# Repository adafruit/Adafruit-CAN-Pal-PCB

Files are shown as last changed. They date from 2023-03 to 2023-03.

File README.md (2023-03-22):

## Adafruit CAN Pal - CAN Bus Transciever - TJA1051T/3 PCB

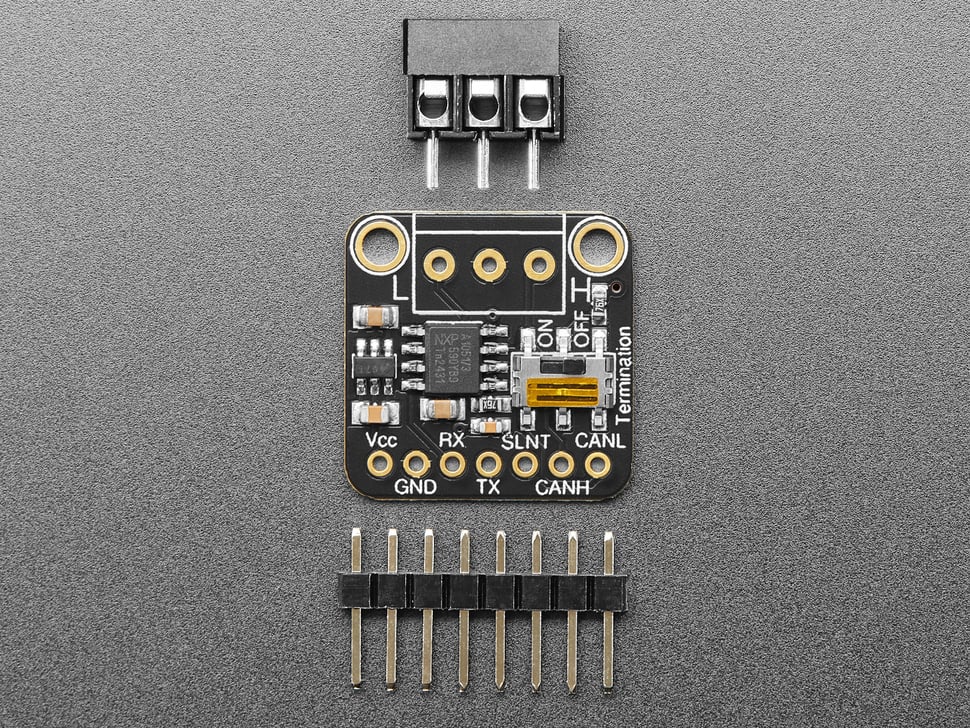
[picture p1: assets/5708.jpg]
<a href="http://www.adafruit.com/products/5708"><br/>
Click here to purchase one from the Adafruit shop</a>

PCB files for the Adafruit CAN Pal - CAN Bus Transciever - TJA1051T/3. 

Format is EagleCAD schematic and board layout
* https://www.adafruit.com/product/5708

### Description

If you'd like to connect a board with native CAN Peripheral support, the Adafruit CAN Pal Transceiver will take the 3V logic level signals and convert them to CAN logic levels with the differential signaling required to communicate. Note that not all chips have a CAN peripheral! Some that we know do have it are the ESP32/ESP32-S2/ESP32-S3 (note that ESP32 calls this interface TWAI not CAN) series of chips, SAME51, STM32F405, or Teensy 4.

Check the product documentation for the board you are wiring this to, to make sure that the chip has CAN support and the RX and TX pins are brought out for you to connect the transceiver to! Despite sharing the 'RX' and 'TX' name with UART, they're not at all the same interface.

CAN Bus is a small-scale networking standard, originally designed for cars and, yes, busses, but is now used for many robotics or sensor networks that need better range and addressing than I2C, and don't have the pins or computational ability to talk on Ethernet. CAN is 2 wire differential, which means it's good for long distances and noisy environments.

Messages are sent at about 1Mbps rate - you set the frequency for the bus and then all 'joiners' must match it, and have an address before the packet so that each node can listen in to messages just for it. New nodes can be attached easily because they just need to connect to the two data lines anywhere in the shared net. Each CAN devices sends messages whenever it wants, and thanks to some clever data encoding, can detect if there's a message collision and retransmit later. 

We've added a few nice extras to this breakout pal to make it useful in many common CAN scenarios:

* TJA1051/T3 can communicate with 3.3V~5V logic for use with modern microcontrollers. 
* 5V charge-pump voltage generator, so even though you are running 3.3V power and logic on most modern microcontroller boards, it will generate a nice clean 5V as required by the transceiver. No separate 5V power required!
* 3.5mm terminal block that can be soldered in to get quick access to the High and Low data lines as well as a ground pin.
* 2 x 60 ohm termination resistor on board (120 ohm in series), you can remove or activate the termination easily by flipping the onboard switch.

Each order comes with an assembled 'pal, terminal block and header. You will need to solder in the header yourself but its a quick task.

### License

Adafruit invests time and resources providing this open source design, please support Adafruit and open-source hardware by purchasing products from [Adafruit](https://www.adafruit.com)!

Designed by Limor Fried/Ladyada for Adafruit Industries.

Creative Commons Attribution/Share-Alike, all text above must be included in any redistribution. 
See license.txt for additional details.

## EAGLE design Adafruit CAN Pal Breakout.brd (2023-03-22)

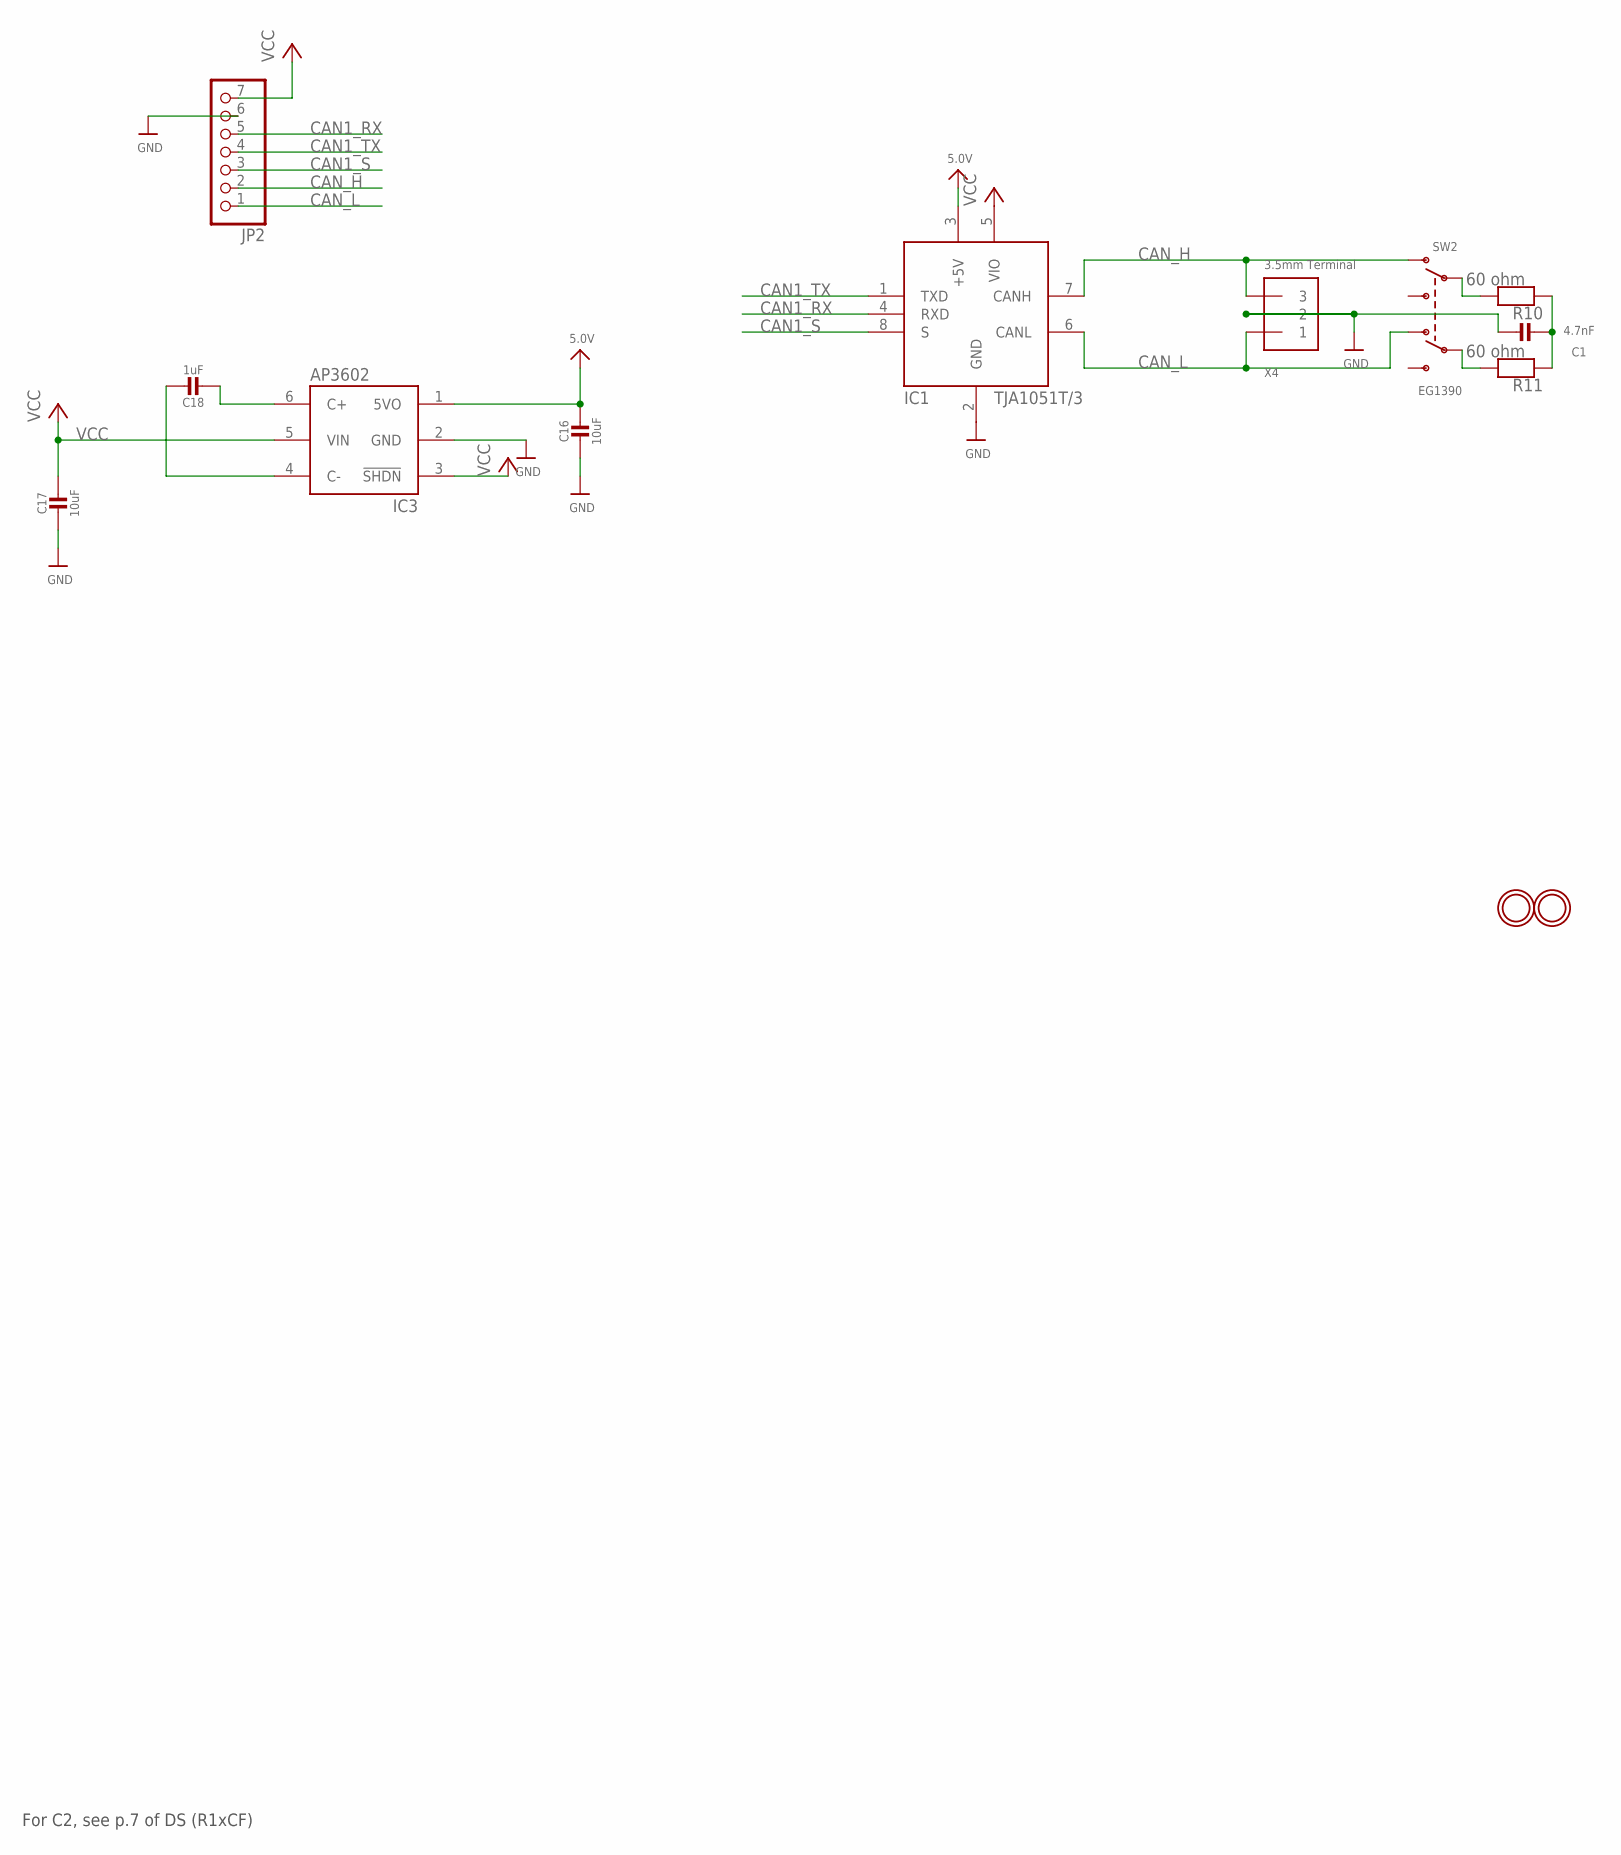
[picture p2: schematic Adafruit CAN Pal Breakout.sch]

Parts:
C1: 4.7nF; 0603-NO
C16, C17: 10uF; 0805-NO
C18: 1uF; 0805_10MGAP
IC1: TJA1051T/3; SOIC8_150MIL
IC3: AP3602; SOT23-6
JP2: HEADER-1X770MIL; 1X07_ROUND_70
R10, R11: 60 ohm; 0603-NO
SW2: EG1390
U$2, U$3: MOUNTINGHOLE2.5; MOUNTINGHOLE_2.5_PLATED
X4: 3.5mm Terminal; TERMBLOCK_1X3-3.5MM

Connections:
5.0V: C16.1, IC1.3 (+5V), IC3.1 (5VO)
CAN1_RX: IC1.4 (RXD), JP2.5
CAN1_S: IC1.8 (S), JP2.3
CAN1_TX: IC1.1 (TXD), JP2.4
CAN_H: IC1.7 (CANH), JP2.2, SW2.O1, X4.3
CAN_L: IC1.6 (CANL), JP2.1, SW2.O2, X4.1
GND: C1.2, C16.2, C17.2, IC1.2 (GND), IC3.2 (GND), JP2.6, X4.2
unnamed: R10.2, SW2.P1
unnamed: R11.2, SW2.P2
unnamed: C18.2, IC3.6 (C+)
unnamed: C18.1, IC3.4 (C-)
unnamed: C1.1, R10.1, R11.1
VCC: C17.1, IC1.5 (VIO), IC3.3 (!SHDN), IC3.5 (VIN), JP2.7

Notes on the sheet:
For C2, see p.7 of DS (R1xCF)

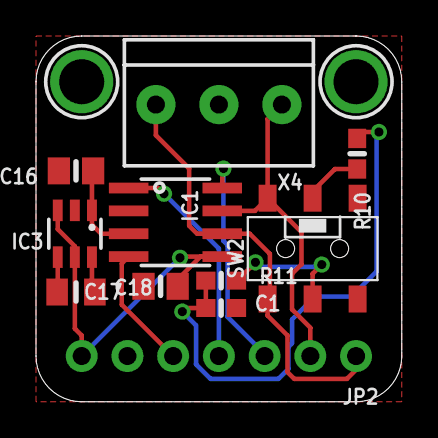
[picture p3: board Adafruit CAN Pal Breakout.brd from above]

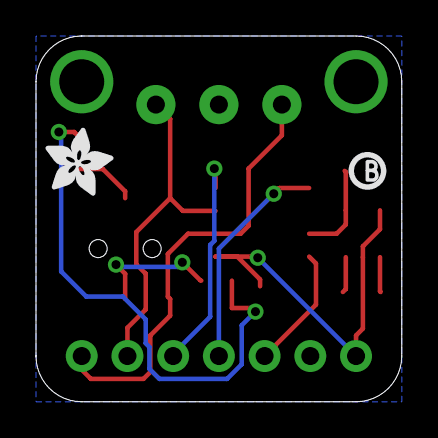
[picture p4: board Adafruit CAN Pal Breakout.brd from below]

Board: 2 copper layers, 20.3 x 20.3 mm, 30 parts (5 on the bottom side), 13 nets.

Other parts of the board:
PLABEL0: PLABEL0
PLABEL1: PLABEL1
PLABEL2: PLABEL2
PLABEL3: PLABEL3
PLABEL4: PLABEL4
PLABEL5: PLABEL5
PLABEL6: PLABEL6
PLABEL7: PLABEL7
PLABEL8: PLABEL8
PLABEL9: PLABEL9
PLABEL10: PLABEL10
PLABEL11: PLABEL11
PLABEL12: PLABEL12
PLABEL13: PLABEL13
PLABEL14: PLABEL14
U$6: ADAFRUIT_3.5MM
U$7: PCBFEAT-REV-040

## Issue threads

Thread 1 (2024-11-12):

Youre shipping the CANPALs with the wrong resistor values

javiBajoCero, 2024-11-12:
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
youre assembling R10 and R11 with 60KOhms instead of 60Ohms in all your boards, i noticed once i had 10 boards put in place and canbus bus impedance was over the roof.

ladyada, 2024-11-15:
we are fixing our stock now, you can email support@adafruit for a replacement!

Closed 2024-11-15.

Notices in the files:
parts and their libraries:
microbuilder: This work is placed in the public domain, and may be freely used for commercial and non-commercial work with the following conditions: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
